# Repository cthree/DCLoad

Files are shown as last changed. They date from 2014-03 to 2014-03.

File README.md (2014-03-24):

DCLoad
======

A Simple DC Constant Current Load Project to build yourself. 

Minimum Specs:

- 20 Watt maximum load (thermal limitation)
- Adjustible current sink up to 30V (relay limitiation)
- Load switch and indicator
- 12 VDC fused power supply with switch and indicator
- Easily modified and expanded
- Modulated dynamic load with function generator (WIP)
- Most sections optional, many jellybean parts

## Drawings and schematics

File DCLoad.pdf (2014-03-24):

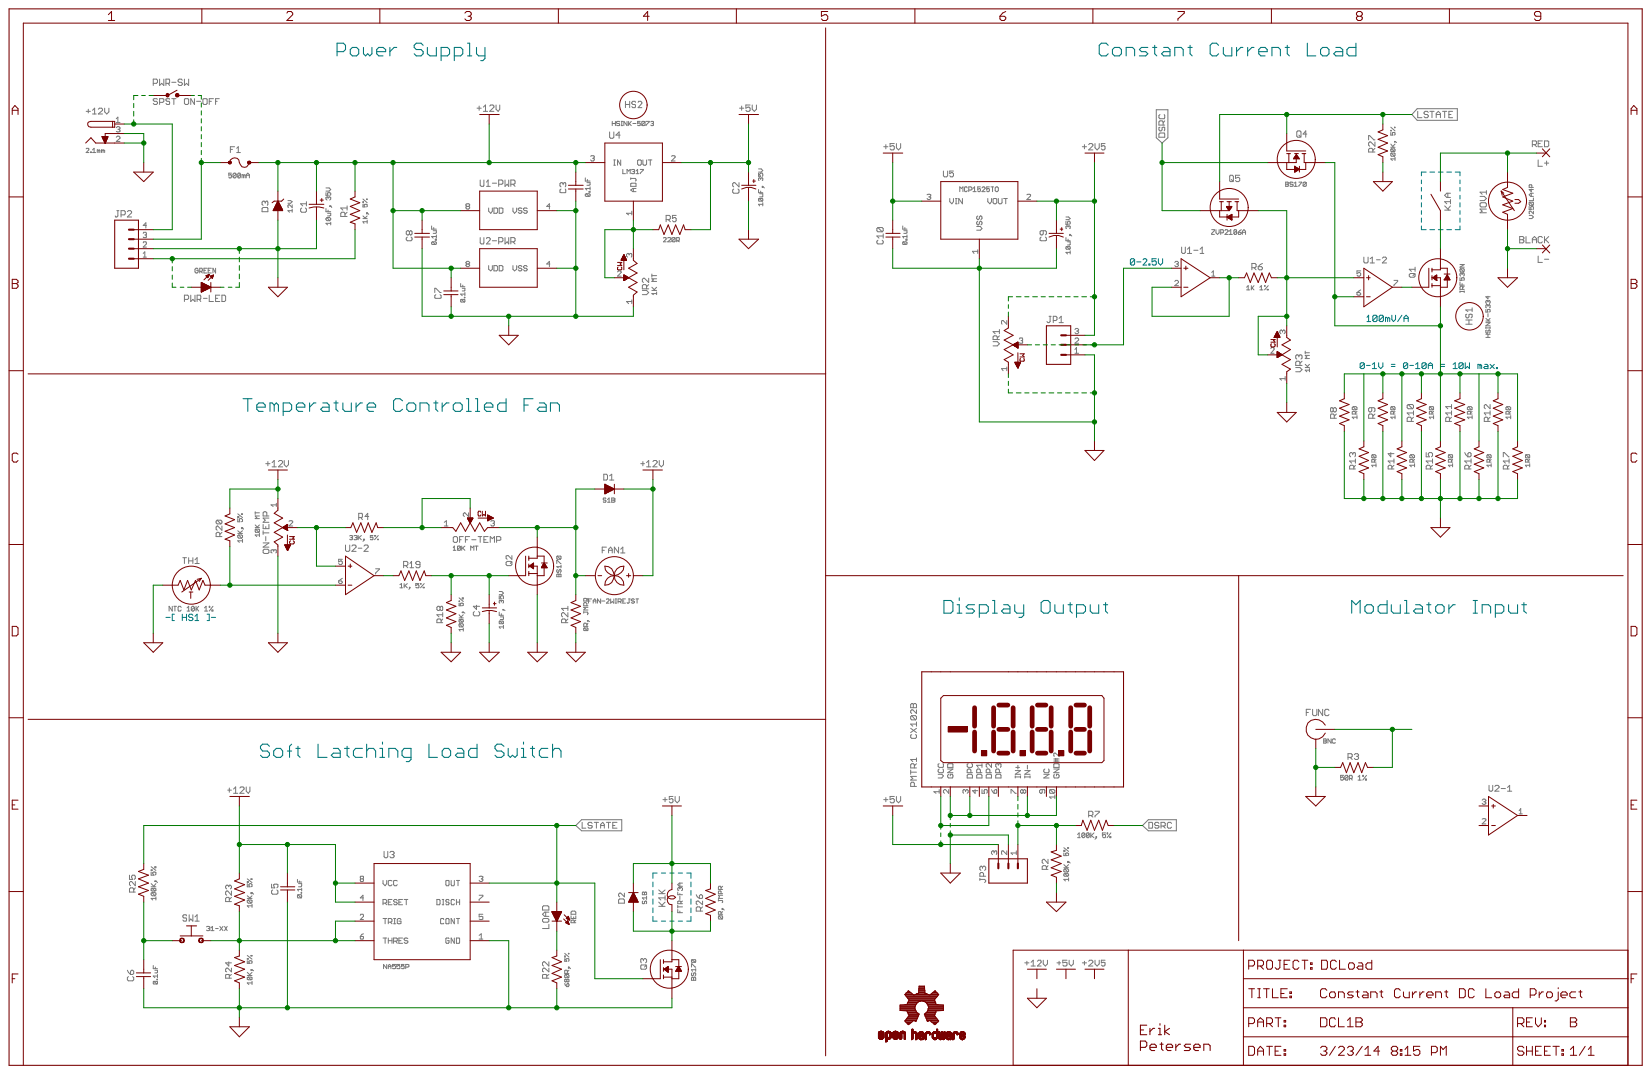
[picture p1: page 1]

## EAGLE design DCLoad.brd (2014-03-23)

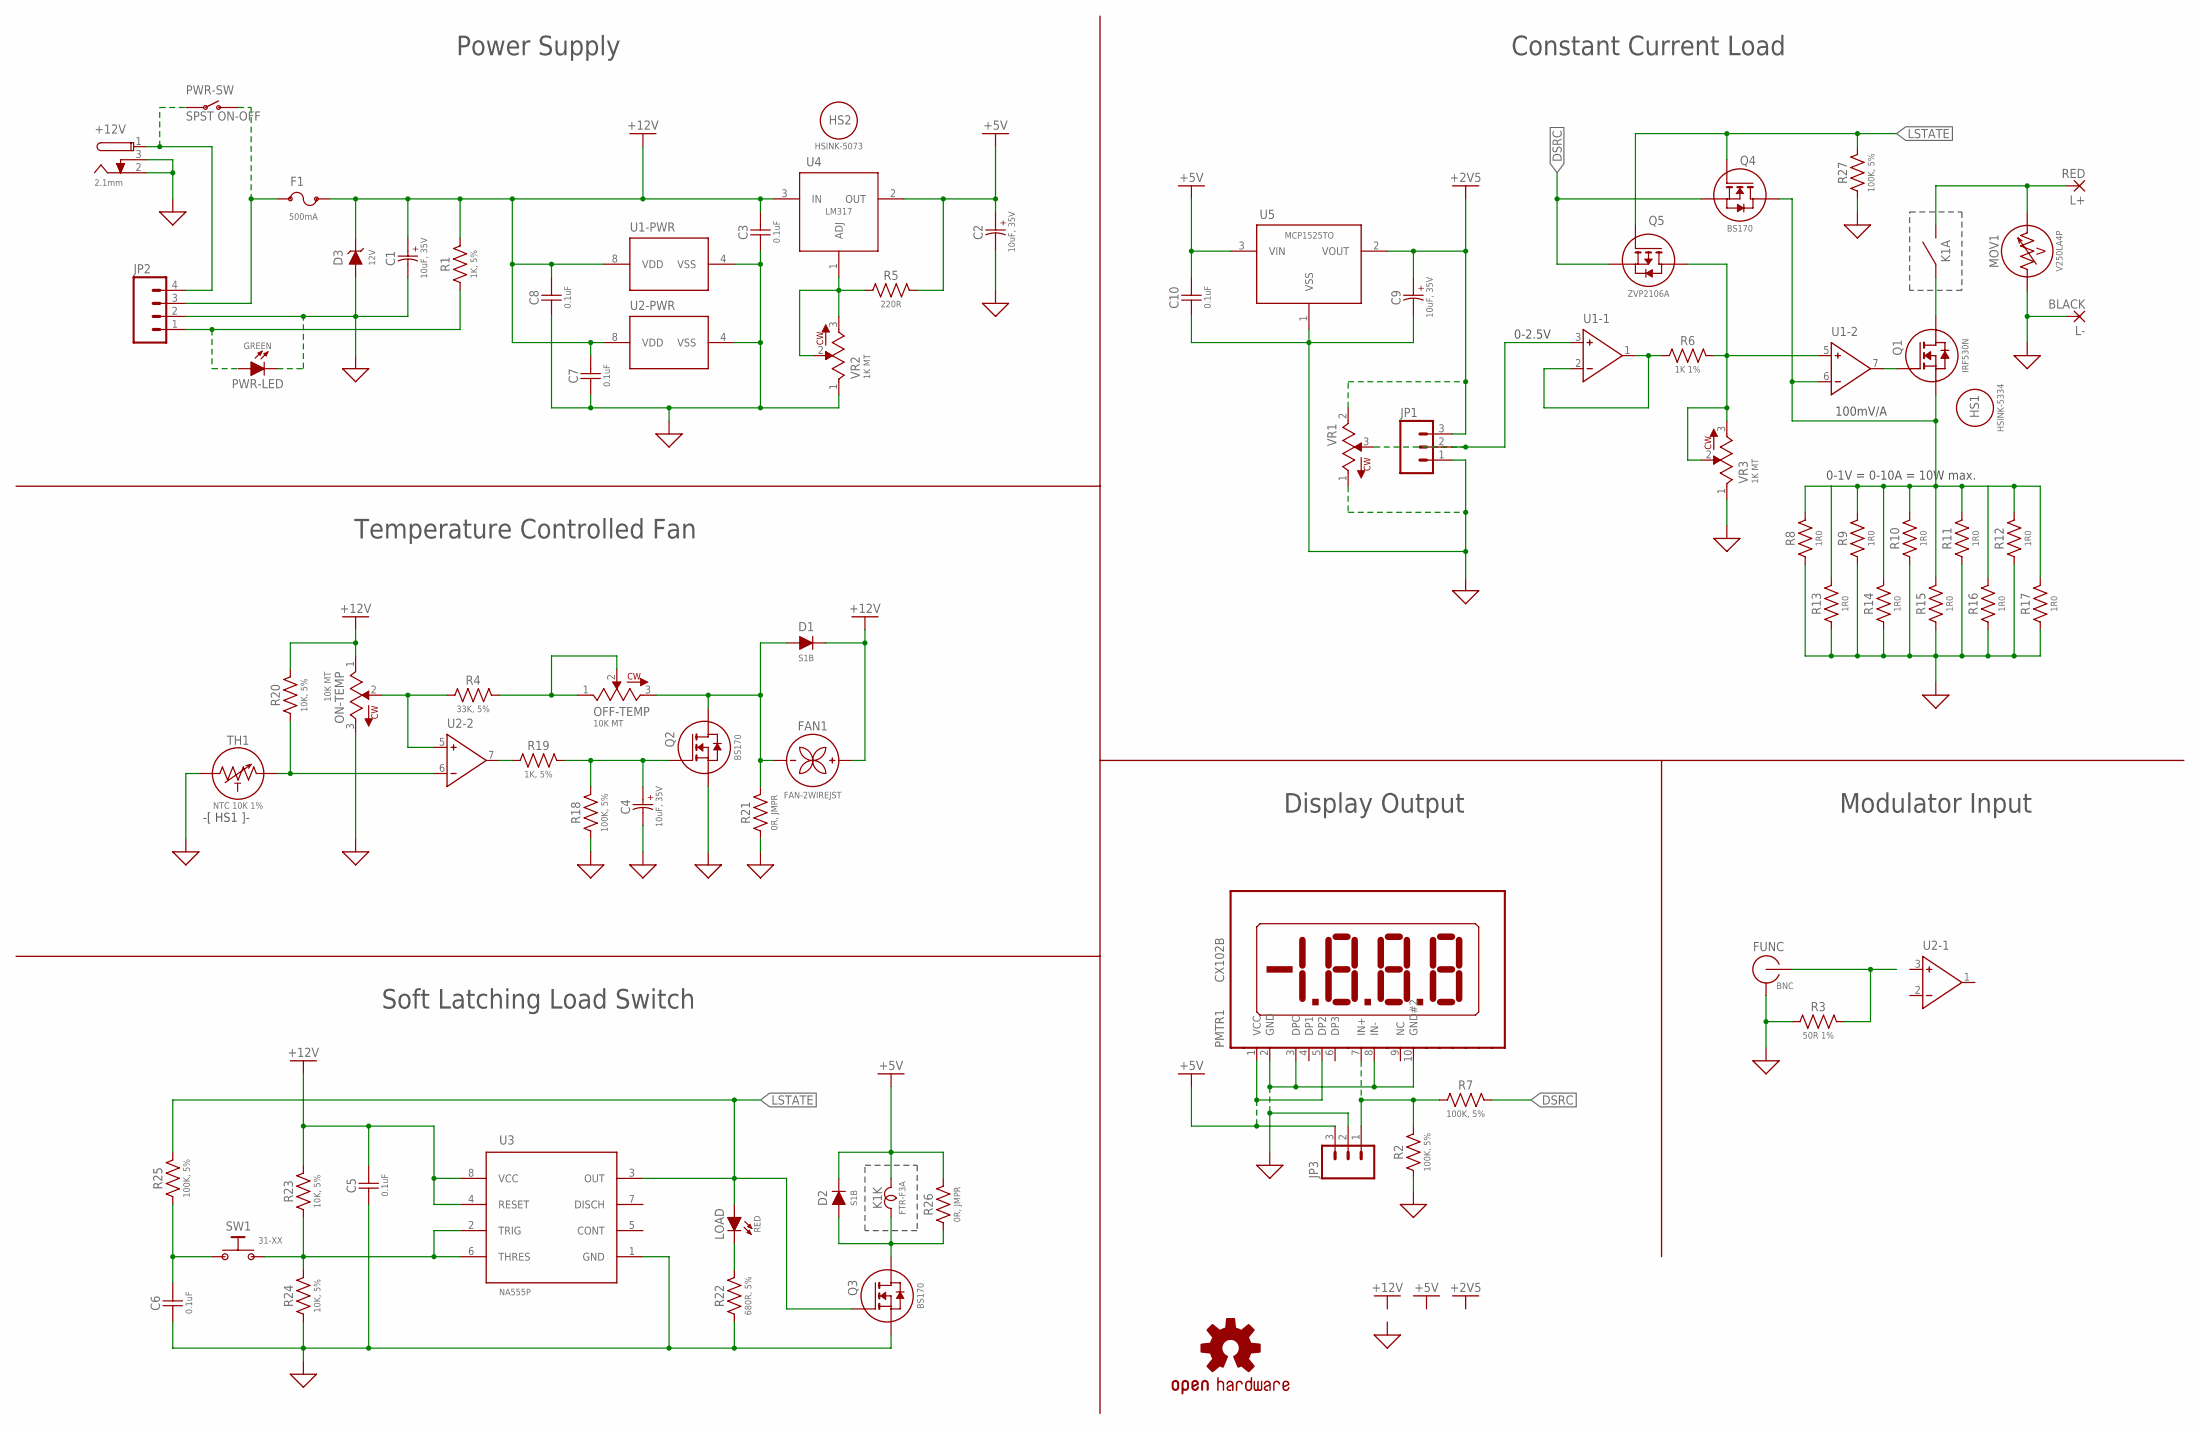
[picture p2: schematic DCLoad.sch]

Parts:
+12V: 2.1mm; PJ-102A
C1, C2, C4, C9: 10uF, 35V; 5RAL
C3, C5, C6, C7, C8, C10: 0.1uF; 18-0603
D1, D2: S1B; DO-214AC
D3: 12V; DO-214AC
F1: 500mA; 1206
FAN1: FAN-2WIREJST; JST-2-PTH
FUNC: BNC
HS1: HSINK-5334; 5334
HS2: HSINK-5073; 5073
JP1, JP3: M03POLAR; MOLEX-1X3
JP2: M04POLAR; MOLEX-1X4
K1: FTR-F3A; FTR-F3STD
L+: RED; 2,54/1,0
L-: BLACK; 2,54/1,0
LOAD: RED; LED5MM
LOGO1: OSHW-LOGOM; OSHW-LOGO-M
MOV1: V250LA4P; S07K17
OFF-TEMP: 10K MT; 3296W
ON-TEMP: 10K MT; 3296W
PMTR1: CX102B; CX102
PWR-LED: GREEN; LED5MM
PWR-SW: SPST ON-OFF; SWITCH-SPST-VERTICAL
Q1: IRF530N; TO220-3
Q2, Q3, Q4: BS170; TO-92
Q5: ZVP2106A; TO-92
R1, R19: 1K, 5%; R0603
R2, R7, R18, R25, R27: 100K, 5%; R0603
R3: 50R 1%; 0204/7
R4: 33K, 5%; R0603
R5: 220R; 0204/7
R6: 1K 1%; 0204/7
R8, R9, R10, R11, R12, R13, R14, R15, R16, R17: 1R0; 2512
R20, R23, R24: 10K, 5%; R0603
R21, R26: 0R, JMPR; R0603
R22: 680R, 5%; R0603
SW1: 31-XX; B3F-31XX
TH1: NTC 10K 1%; BEAD-THERM
U1, U2: TLC272ACP; PDIP-8
U3: NA555P; DIP254P762X508-8
U4: LM317; TO-220AB
U5: MCP1525TO; TO127P254X495-3
VR1: 10TPOT
VR2, VR3: 1K MT; 3296W

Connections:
+5V: C2.P, D2.C, JP3.3, K1.2, PMTR1.1 (VCC), PMTR1.5 (DP2), R5.2, R26.2, U4.2 (OUT)
+12V: C1.P, C3.2, C5.2, C7.2, C8.2, C10.2, D1.C, D3.C, F1.2, FAN1.2 (NEG(-)), ON-TEMP.1, R1.2, R20.2, R23.2, U1.8 (VDD), U2.8 (VDD), U3.4 (RESET), U3.8 (VCC), U4.3 (IN), U5.3 (VIN)
DSRC: Q4.3 (S), Q5.3 (S), R7.2
GND: +12V.2, +12V.3, C1.N, C2.N, C3.1, C4.N, C5.1, C6.1, C7.1, C8.1, C9.N, C10.1, D3.A, FUNC.GND, JP1.1, JP2.2, JP3.2, L-.1, MOV1.2, ON-TEMP.3, PMTR1.2 (GND), PMTR1.3 (DPC), PMTR1.8 (IN-), PMTR1.10 (GND#2), PWR-LED.K (C), Q2.3 (S), Q3.3 (S), R2.1, R3.1, R8.1, R9.1, R10.1, R11.1, R12.1, R13.1, R14.1, R15.1, R16.1, R17.1, R18.1, R21.1, R22.1, R24.1, R27.1, SW1.GND@1 (GND), SW1.GND@2 (GND), TH1.P$1 (1), U1.4 (VSS), U2.4 (VSS), U3.1 (GND), U5.1 (VSS), VR1.1 (3), VR2.1, VR3.1
LSTATE: LOAD.A, Q3.2 (G), Q4.2 (G), Q5.2 (G), R25.2, R27.2, U3.3 (OUT)
unnamed: FUNC.S (OUT), R3.2
unnamed: +12V.1, JP2.4, PWR-SW.2
unnamed: Q1.1 (G), U1.7 (OUT)
unnamed: R5.1, U4.1 (ADJ), VR2.2, VR2.3
unnamed: K1.4 (2), L+.1, MOV1.1
unnamed: D1.A, FAN1.1 (POS(+)), OFF-TEMP.3, Q2.1 (D), R21.2
unnamed: R20.1, TH1.P$2 (2), U2.6 (IN-)
unnamed: ON-TEMP.2, R4.1, U2.5 (IN+)
unnamed: R19.1, U2.7 (OUT)
unnamed: D2.A, K1.1, Q3.1 (D), R26.1
unnamed: C4.P, Q2.2 (G), R18.2, R19.2
unnamed: OFF-TEMP.1, OFF-TEMP.2, R4.2
unnamed: C6.2, R25.1, SW1.1
unnamed: R6.1, U1.1 (OUT), U1.2 (IN-)
unnamed: LOAD.K (C), R22.2
unnamed: R23.1, R24.2, SW1.2, U3.2 (TRIG), U3.6 (THRES)
unnamed: F1.1, JP2.3, PWR-SW.1 (O)
unnamed: JP1.2, U1.3 (IN+), VR1.3 (2)
unnamed: K1.3 (1), Q1.2 (D)
unnamed: JP3.1, PMTR1.7 (IN+), R2.2, R7.1
unnamed: JP2.1, PWR-LED.A, R1.1
SENSE: Q1.3 (S), Q4.1 (D), R8.2, R9.2, R10.2, R11.2, R12.2, R13.2, R14.2, R15.2, R16.2, R17.2, U1.6 (IN-)
SET: Q5.1 (D), R6.2, U1.5 (IN+), VR3.2, VR3.3
VREF: C9.P, JP1.3, U5.2 (VOUT), VR1.2 (1)

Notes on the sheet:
-[ HS1 ]-
Constant Current Load
Power Supply
Temperature Controlled Fan
Soft Latching Load Switch
0-2.5V
100mV/A
0-1V = 0-10A = 10W max.
Modulator Input
Display Output

Board: 2 copper layers, 75 parts (0 on the bottom side), 29 nets, no tracks yet.

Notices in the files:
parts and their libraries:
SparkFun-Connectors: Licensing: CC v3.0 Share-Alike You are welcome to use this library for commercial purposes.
